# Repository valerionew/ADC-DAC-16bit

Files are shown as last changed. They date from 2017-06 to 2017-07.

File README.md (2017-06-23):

# ADC-DAC-16bit

Released under CC-BY-SA 4.0 license  


### Project status
At this time, the board is mounted and waiting to be tested 

### Project description 
An easy and cheap board to prototypate with two dual channel 16 bit A/D and D/A converters.  
Makes use of I2C to communicate with a microcontroller, see the datasheets for reference.  
Drawn in KiCAD.

Makes use of:
* **MCP3426** 16 bit ADC, dual channel, differential
* **AD5667R** 16 bit DAC, dual channel (the R at the end is important)
* 2 100nF 0603 capacitors
* 2 100nF 0805 capacitors
* 2 10uF  1206 capacitors
* 2 4k7   0805 resistors  

But look how cute it is  
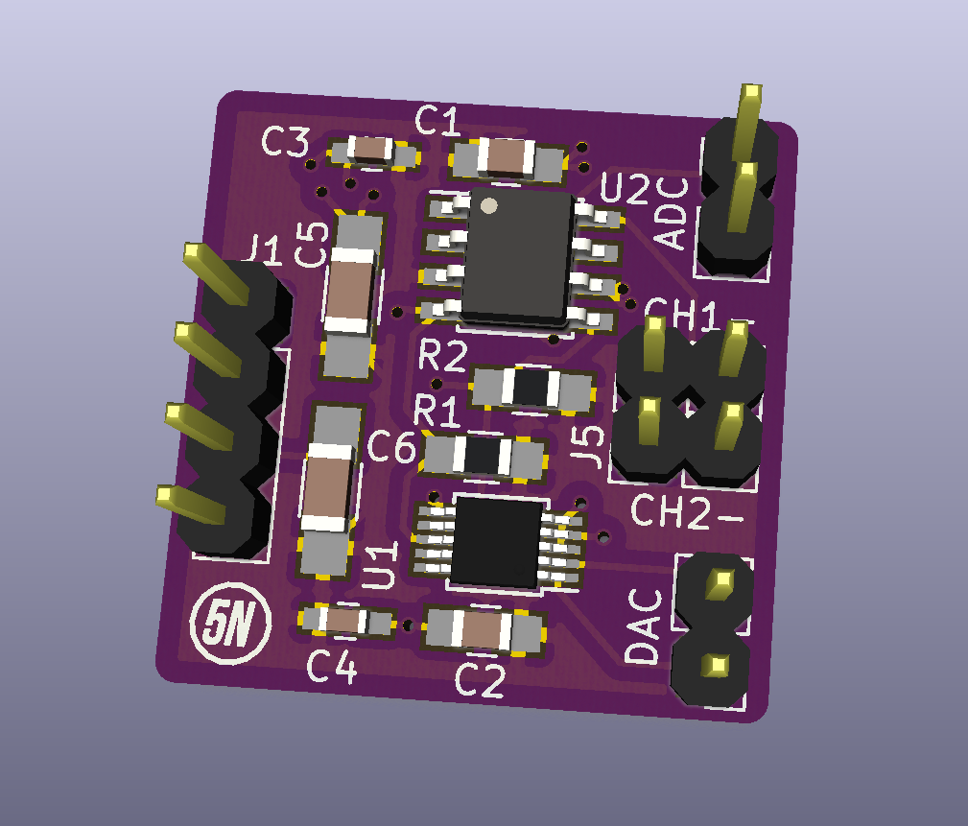
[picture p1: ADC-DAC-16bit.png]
Board 3D View


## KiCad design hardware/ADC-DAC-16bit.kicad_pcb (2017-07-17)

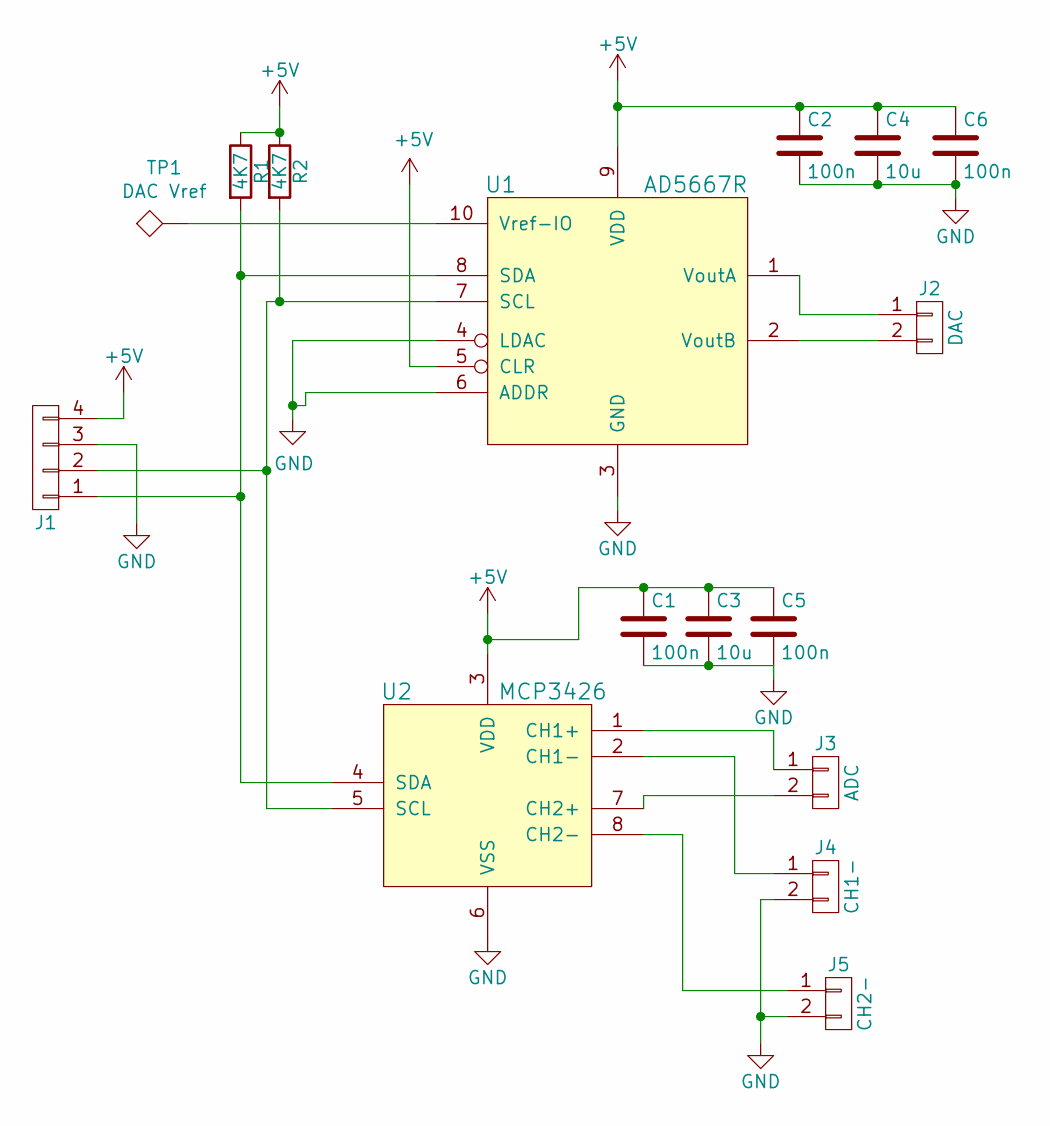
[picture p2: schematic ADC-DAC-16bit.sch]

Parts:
C1, C2: 100n; C_0805_HandSoldering
C3, C4: 10u; C_1206_HandSoldering
C5, C6: 100n; C_0603_HandSoldering
J1: CON; Pin_Header_Straight_1x04_Pitch2.54mm
J2: DAC; Pin_Header_Straight_1x02_Pitch2.54mm
J3: ADC; Pin_Header_Straight_1x02_Pitch2.54mm
J4: CH1-; Pin_Header_Straight_1x02_Pitch2.54mm
J5: CH2-; Pin_Header_Straight_1x02_Pitch2.54mm
R1, R2: 4K7; R_0805_HandSoldering
TP1: DAC Vref; Measurement_Point_Round-SMD-Pad_Small
U1: AD5667R; MSOP-10_3x3mm_Pitch0.5mm
U2: MCP3426; SOIC-8_3.9x4.9mm_Pitch1.27mm

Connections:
+5V: C1.1, C2.1, C3.1, C4.1, C5.1, C6.1, J1.4, R1.1, R2.1, U1.5 (CLR), U1.9 (VDD), U2.3 (VDD)
GND: C1.2, C2.2, C3.2, C4.2, C5.2, C6.2, J1.3, J4.2, J5.2, U1.3 (GND), U1.4 (LDAC), U1.6 (ADDR), U2.6 (VSS)
unnamed: J1.1, R1.2, U1.8 (SDA), U2.4 (SDA)
unnamed: J1.2, R2.2, U1.7 (SCL), U2.5 (SCL)
unnamed: J2.1, U1.1 (VoutA)
unnamed: J2.2, U1.2 (VoutB)
unnamed: J3.1, U2.1 (CH1+)
unnamed: J3.2, U2.7 (CH2+)
unnamed: J4.1, U2.2 (CH1-)
unnamed: J5.1, U2.8 (CH2-)
unnamed: TP1.1, U1.10 (Vref-IO)

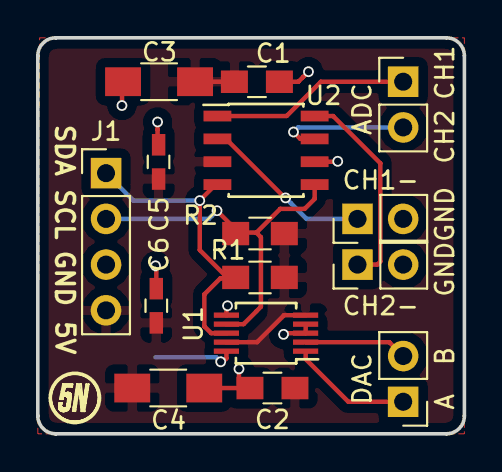
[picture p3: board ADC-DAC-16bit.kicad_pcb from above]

Board: 2 copper layers, 23.7 x 22.0 mm, 16 parts (1 on the bottom side), 11 nets.

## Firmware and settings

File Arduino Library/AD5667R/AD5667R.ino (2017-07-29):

#include <Wire.h>

#include "AD5667R.h"

AD5667R dac; //use default i2c address
//AD5667R dac(0xAA); //use 0xAA as i2c address

void setup() {
  Serial.begin(115200);
  Wire.begin(); //master
  Serial.println("start");



  uint8_t error = dac.setReference(Dac::BOTH, Reference::_EXTERNAL);
  if ( !error )
    Serial.println("set internal reference");
  else
    Serial.println("error setting reference adc");

  error = dac.setLdac(Dac::BOTH, Ldac::DISABLE);
  if ( !error )
    Serial.println("disaled ldac");
  else
    Serial.println("error setting ldac");  

}

void loop() {
  uint8_t error;
  error = dac.setOutput(Dac::BOTH, 0xFFFF);
  if ( !error )
    Serial.println("output set 0xFFFF");
  else
    Serial.println("error setting output to 0xFFFF");  
  
  delay(5000);

  error = dac.setOutput(Dac::BOTH, 0x00);
  if ( !error )
    Serial.println("output set 0x00");
  else
    Serial.println("error setting output to 0x00");  

  delay(5000);

  error = dac.setOutput(Dac::BOTH, 0x00FF);
  if ( !error )
    Serial.println("output set 0x00FF");
  else
    Serial.println("error setting output to 0x00FF");  

  delay(5000);
}

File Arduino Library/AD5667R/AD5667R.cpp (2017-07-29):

#include "AD5667R.h"

#define AD5667R_MASK_BYTE_SELECTION 0x40


AD5667R::AD5667R(uint8_t i2cAddress):
  address(i2cAddress)
{  
}

uint8_t AD5667R::sendCommand(uint8_t selection, Command command, Dac dac, uint8_t high, uint8_t low, uint64_t timeout){
  uint8_t header = 0;
  if (selection){
    header |= AD5667R_MASK_BYTE_SELECTION;
  }

  header |= static_cast<uint8_t>(command);

  header |= static_cast<uint8_t>(dac);

  Wire.beginTransmission(address);
  Wire.write(header);
  Wire.write(high);
  Wire.write(low);
  Wire.endTransmission();
  
  if (!timeout){
    //if timeout is 0, we dont want to verify the command success. we always return success (0)
    return 0;
  }

  Wire.requestFrom(0x0F, 3);
  
  uint64_t start = micros();
  while (Wire.available() < 3 && micros() - start < timeout) {
    delayMicroseconds(1);
  }
  if (micros() - start >= timeout){
    return 1;
  }
  if (Wire.read() != header){
    return 2;
  }
  if (Wire.read() != high){
    return 3;
  }
  if (Wire.read() != low){
    return 4;
  }

  return 0;
}

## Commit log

2017-06-03 Added project files
    [ADC-DAC-16bit.kicad_pcb, ADC-DAC-16bit.sch]
2017-07-17 moved file
    [ADC-DAC-16bit.sch]
2017-07-17 v0.2 update
    [ADC-DAC-16bit.kicad_pcb, ADC-DAC-16bit.sch]
2017-07-29 changed static method to normal method, ivin possibility to override the default i2c address.

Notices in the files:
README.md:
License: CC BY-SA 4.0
